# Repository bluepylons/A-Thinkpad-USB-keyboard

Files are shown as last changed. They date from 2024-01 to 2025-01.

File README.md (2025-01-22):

# Work in Progress

## Note January 21, 2025: the downstream USB-C port likely violates USB-C spec since it provides 5V all the time, instead of only when CC resistors are detected.

# About

This is a project attempting to make a USB keyboard/Trackpoint controller and enclosure for the non-chiclet Thinkpad keyboard (from the 10/20 generation, such as the T410, W520, etc.). These were, in my opinion, the best Thinkpad keyboards ever made.

# Controller

The current plan is to use an RP2040 microcontroller running QMK to handle the key matrix scanning and Trackpoint. I would also like to add a USB 2.0 hub.

# Future goals

I would like to eventually adapt this keyboard to be used on the Framework 13 laptop, which would require designing a custom lower chassis for the Framework laptop. That is well in the future, but the engineering required for this project lays much of the groundwork for that project.

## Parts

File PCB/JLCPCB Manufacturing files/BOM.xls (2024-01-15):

Comment | Designator | Footprint | LCSC Part Number | Type
10uF | C1, C2, C14,C15,C16,C17,C18,C19,C20, C25, C32,C33,C34 | C1206 | C13585 (https://lcsc.com/product-detail/Multilayer-Ceramic-Capacitors-MLCC-SMD-SMT_SAMSUNG_CL31A106KBHNNNE_10uF-106-10-50V_C13585.html) | Basic
18pF | C3, C4 | C0402 | C1549 | Basic
22pF | C5, C9 | C0402 | C1555 | Basic
100nF | C6,C7,C8, C10,C11,C12,C13, C22,C23,C24, C26,C27,C28, C30, C31 | C0402 | C1525 | Basic
1uF | C21,C29 | C0603 | C15849 | Basic
SMF9.0CA | D1 | SOD-123FL | C123799 | Extended
RB060M-60TR (https://jlcpcb.com/partdetail/RohmSemicon-RB060M60TR/C114257) | D3,D4 | SOD-123F | C114257 | Extended
1812L075PR | F1 | 1812 | C142689 | Extended
TYPE-C-31-M-12 | J1,J7 | SMD | C165948 | Extended
CBM321611U600T | L1 | 1206 | C394451 | Extended
BSS138 | Q1,Q2,Q3 | SOT-23 | C52895 | Extended
5.1K | R1, R2 | R0805 | C27834 (https://lcsc.com/product-detail/Chip-Resistor-Surface-Mount_UNI-ROYAL-Uniroyal-Elec-0805W8F5101T5E_C27834.html) | Basic
27 | R3,R13 | R0402 | C2991567 | Extended
10K | R4, R11, R20,R21,R22,R23 | R0603 | C25804 | Basic
12K | R5 | R0805 | C17444 | Basic
56K | R6,R7,R8,R9 | R0805 | C17756 | Extended
100 | R10,R18 | R0805 | C17408 | Basic
100k | R12 | R0805 | C149504 | Basic
1k | R14,R15,R16 | R0805 | C17513 | Basic
1M | R19 | R0805 | C17514 | Basic
SRV05-4 | U1,U4,U5,U10 | SOT-23-6 | C7420376 | Extended
RP2040 | U2 | LQFN-56(7x7) | C2040 | Extended
USB2514B-AEZC-TR (https://jlcpcb.com/partdetail/MicrochipTech-USB2514B_AEZCTR/C16251) | U3 | VQFN-36-EP(6x6) | C16251 | Extended
W25Q128JVS | U6 | SOIC-8-208mil | C97521 | Basic
TLV1117LV33DCYR | U8 | SOT-223 | C15578 | Extended
24MHz | Y1 | SMD3225-4P | C91744 | Extended
12MHz | Y2 | SMD3225-4P | C9002 | Basic

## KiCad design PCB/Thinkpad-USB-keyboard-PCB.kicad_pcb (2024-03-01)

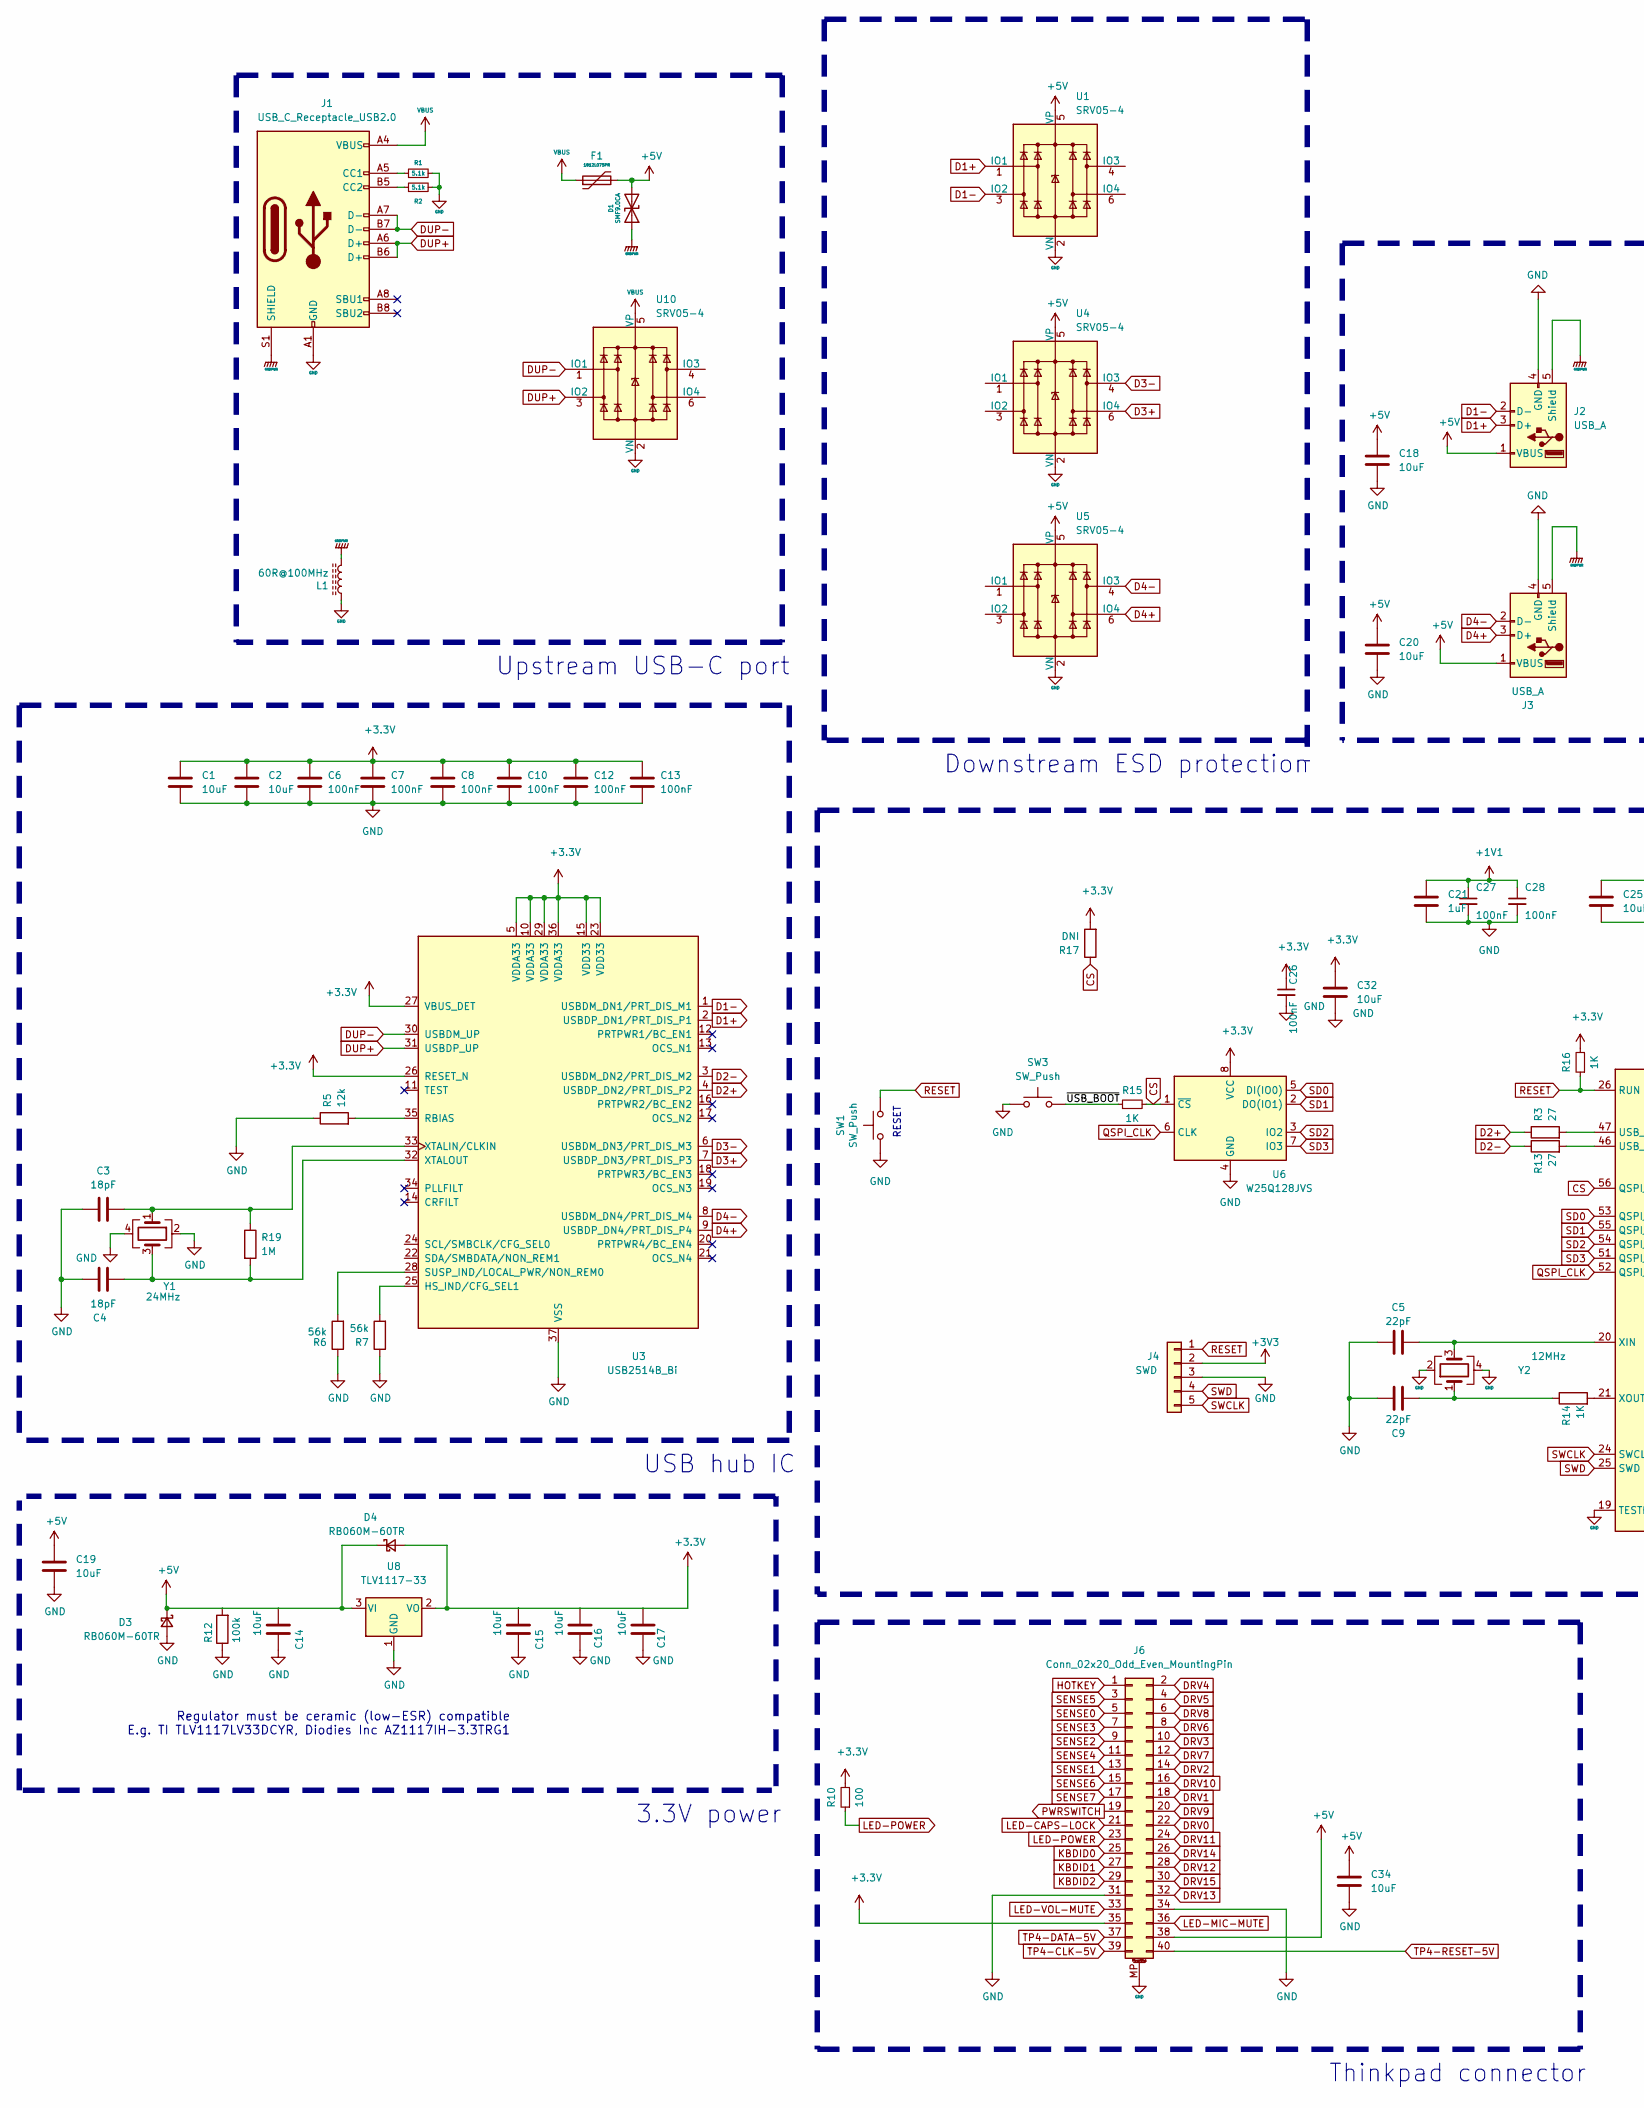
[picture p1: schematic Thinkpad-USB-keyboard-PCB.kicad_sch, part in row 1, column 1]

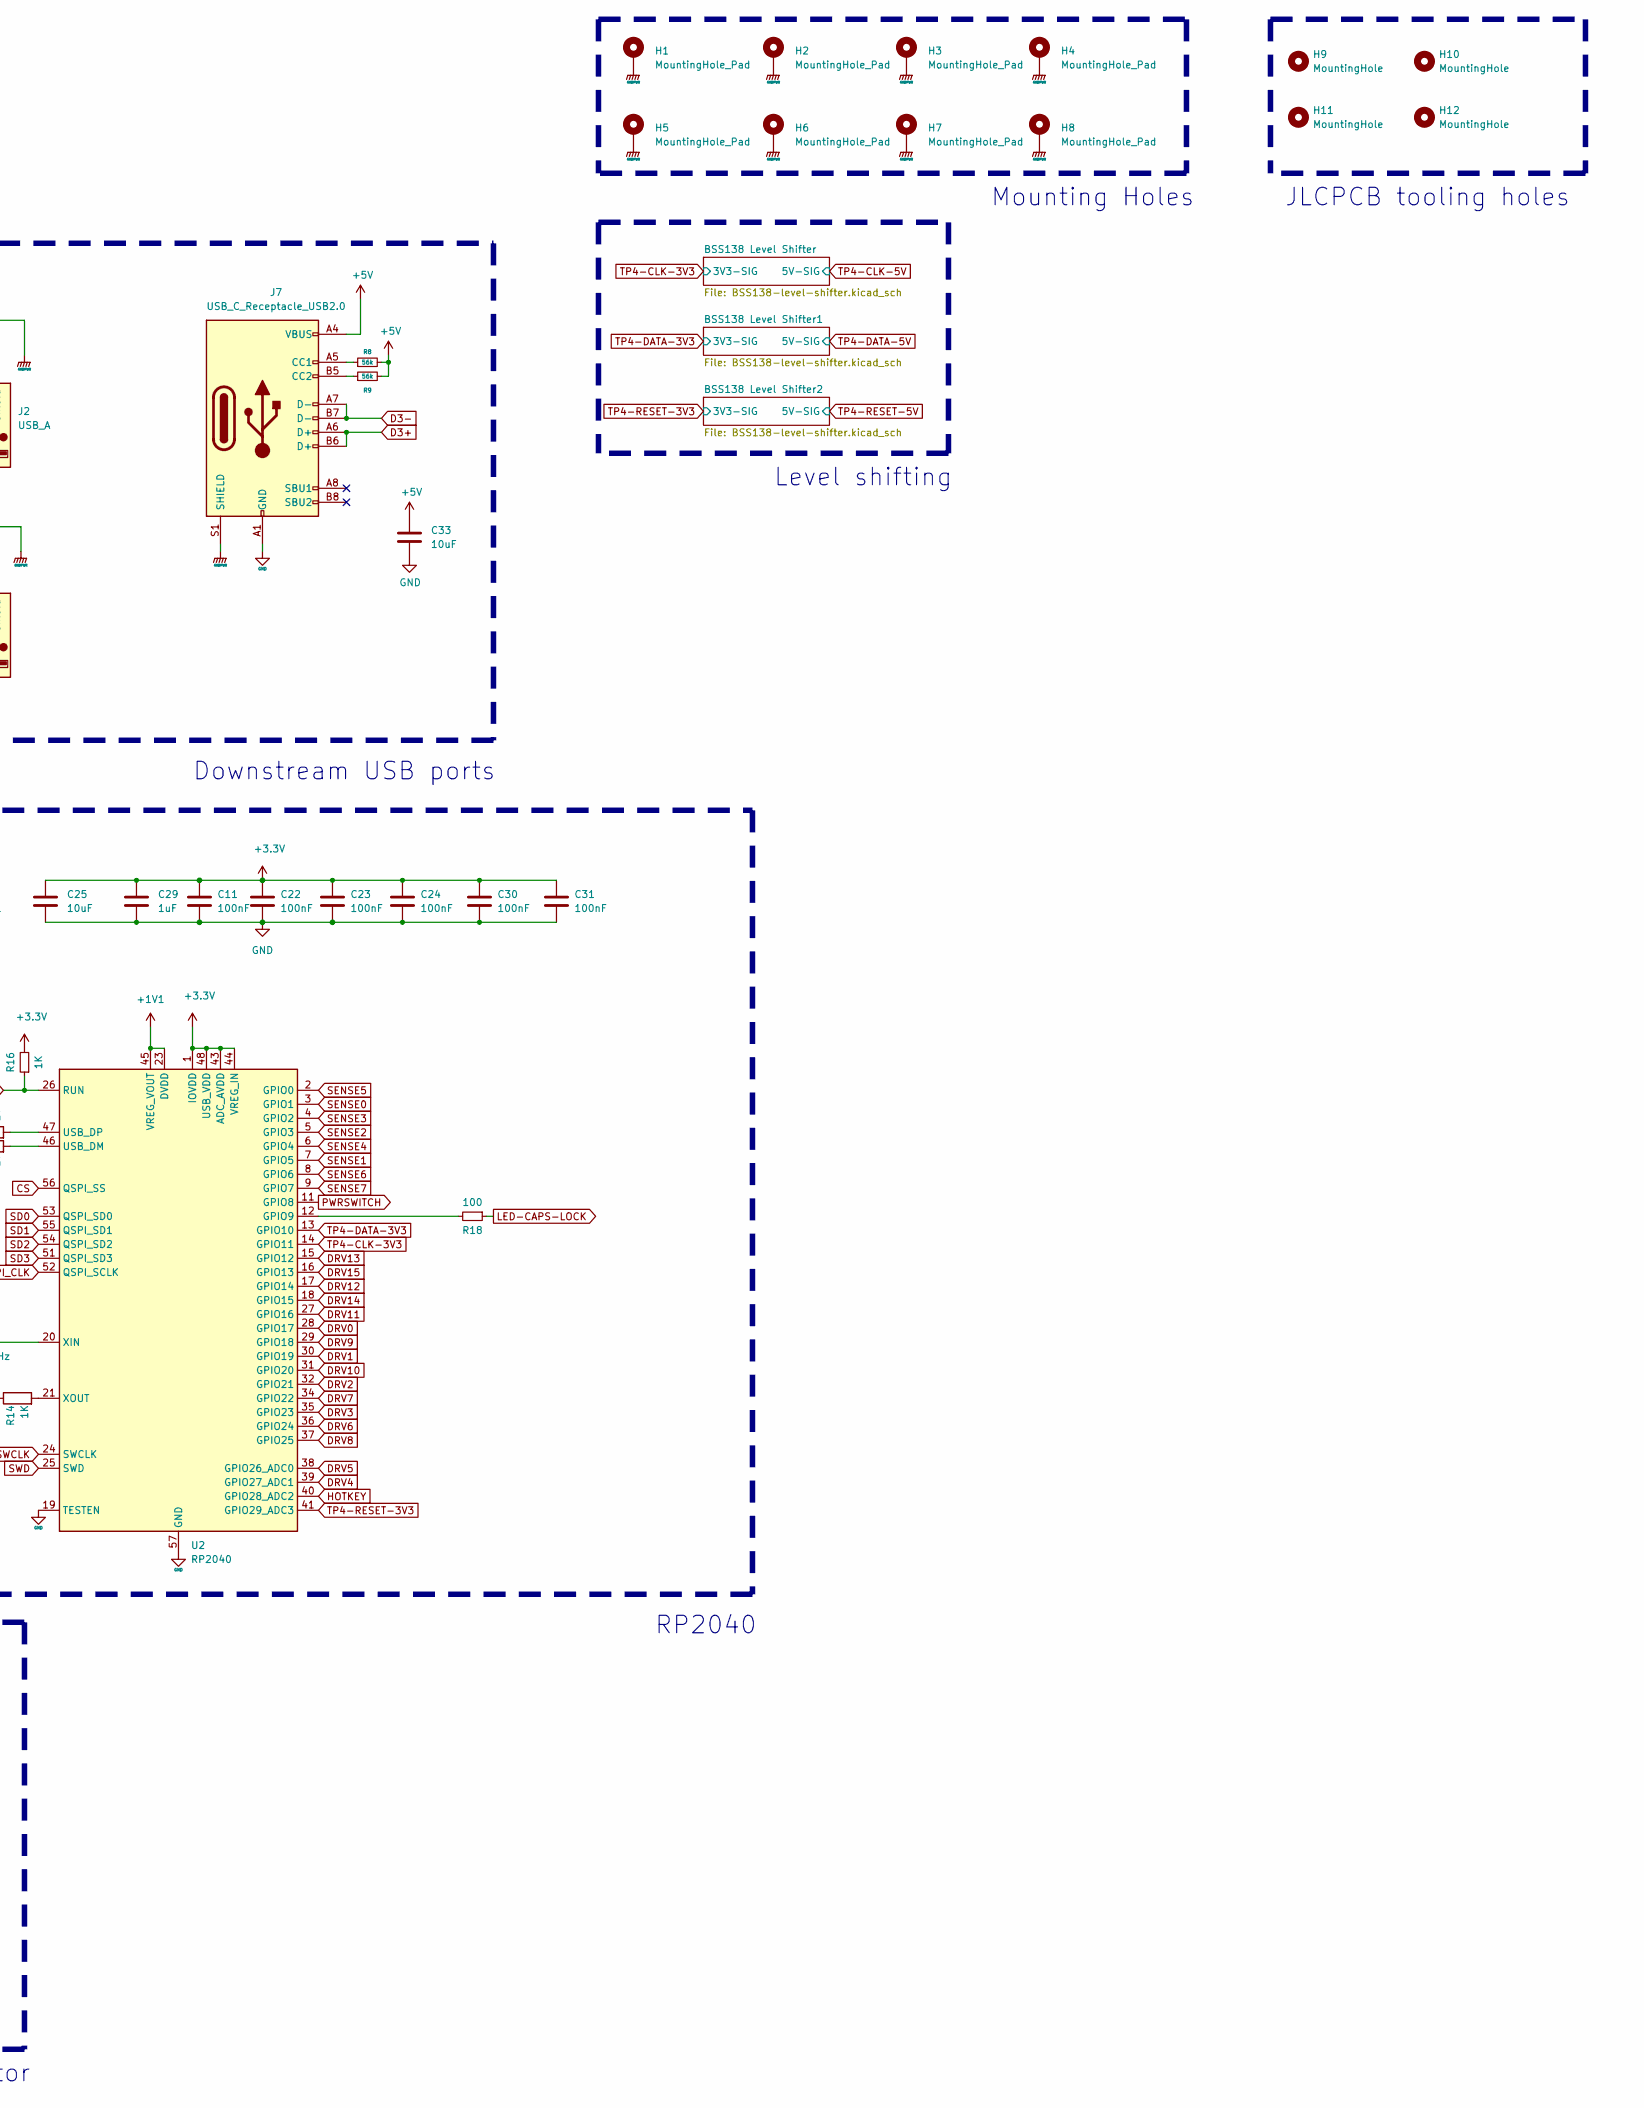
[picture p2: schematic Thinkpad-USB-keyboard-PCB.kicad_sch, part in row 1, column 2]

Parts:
C1, C2, C14, C15, C16, C17, C18, C19, C20, C25, C32, C33, C34: 10uF; C_1206_3216Metric_Pad1.33x1.80mm_HandSolder
C3, C4: 18pF; C_0402_1005Metric_Pad0.74x0.62mm_HandSolder
C5, C9: 22pF; C_0402_1005Metric_Pad0.74x0.62mm_HandSolder
C6, C7, C8, C10, C11, C12, C13, C22, C23, C24, C30, C31: 100nF; C_0402_1005Metric_Pad0.74x0.62mm_HandSolder
C21, C29: 1uF; C_0603_1608Metric_Pad1.08x0.95mm_HandSolder
C26, C27, C28: 100nF; C_0402_1005Metric_Pad0.74x0.62mm_HandSolder; LCSC C1525
D1: SMF9.0CA; D_SOD-123; Manufacturer Part No SMF9.0CA; LCSC Part No C123799
D3, D4: RB060M-60TR; D_SOD-123
F1: 1812L075PR; Fuse_1812_4532Metric_Pad1.30x3.40mm_HandSolder; Manufacturer Part No ASMD1206-150; LCSC Part No C135342
H1, H2, H3, H4, H5, H6, H7, H8: MountingHole_Pad; MountingHole_3.2mm_M3_ISO7380_Pad
H9, H10, H11, H12: MountingHole; JLCPCB-tooling-hole
J1, J7: USB_C_Receptacle_USB2.0; USB_C_Receptacle_HRO_TYPE-C-31-M-12; LCSC C165948
J2, J3: USB_A; USB_A_Molex_67643_Horizontal
J4: SWD; PinSocket_1x05_P2.54mm_Vertical
J6: Conn_02x20_Odd_Even_MountingPin; Molex Slimstack 54363-0489
L1: 60R@100MHz; L_1206_3216Metric; Manufacturer Part No MLB3216-600P4A(f); LCSC Part No C33600
R1, R2: 5.1k; R_0805_2012Metric_Pad1.20x1.40mm_HandSolder
R3, R13: 27; C_0402_1005Metric_Pad0.74x0.62mm_HandSolder
R5: 12k; R_0805_2012Metric_Pad1.20x1.40mm_HandSolder
R6, R7, R8, R9: 56k; R_0805_2012Metric_Pad1.20x1.40mm_HandSolder
R10, R18: 100; R_0805_2012Metric_Pad1.20x1.40mm_HandSolder; LCSC C11702
R12: 100k; R_0805_2012Metric_Pad1.20x1.40mm_HandSolder
R14: 1K; R_0805_2012Metric_Pad1.20x1.40mm_HandSolder
R15, R16: 1K; R_0805_2012Metric_Pad1.20x1.40mm_HandSolder; LCSC C11702
R17: DNI; C_0805_2012Metric_Pad1.18x1.45mm_HandSolder
R19: 1M; R_0805_2012Metric_Pad1.20x1.40mm_HandSolder
SW1, SW3: SW_Push; SW_PUSH_6mm_H5mm
U1, U4, U5, U10: SRV05-4; SOT-23-6
U2: RP2040; QFN-56-1EP_7x7mm_P0.4mm_EP3.2x3.2mm
U3: USB2514B_Bi; QFN-36-1EP_6x6mm_P0.5mm_EP3.7x3.7mm
U6: W25Q128JVS; SOIC-8_5.23x5.23mm_P1.27mm; LCSC C131025
U8: TLV1117-33; SOT-223-3_TabPin2
Y1: 24MHz; Crystal_SMD_3225-4Pin_3.2x2.5mm_HandSoldering
Y2: 12MHz; Crystal_SMD_3225-4Pin_3.2x2.5mm_HandSoldering

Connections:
+1V1: C21.1, C27.1, C28.1, U2.23 (DVDD), U2.45 (VREG_VOUT), U2.50 (DVDD)
+5V: C14.1, C18.1, C19.1, C20.1, C33.1, C34.1, D1.2 (A2), D3.1 (K), D4.1 (K), F1.2, J2.1 (VBUS), J3.1 (VBUS), J6.38, J7.A4 (VBUS), J7.A9 (VBUS), J7.B4 (VBUS), J7.B9 (VBUS), R8.2, R9.2, R12.2, U1.5 (VP), U4.5 (VP), U5.5 (VP), U8.3 (VI); also elsewhere on the board
/~USB_BOOT: R15.1, SW3.2
CS: R15.2, R17.1, U2.56 (QSPI_SS), U6.1 (~CS)
D1+: J2.3 (D+), U1.1 (IO1), U3.2 (USBDP_DN1/PRT_DIS_P1)
D1-: J2.2 (D-), U1.3 (IO2), U3.1 (USBDM_DN1/PRT_DIS_M1)
D2+: R3.1, U3.4 (USBDP_DN2/PRT_DIS_P2)
D2-: R13.1, U3.3 (USBDM_DN2/PRT_DIS_M2)
D3+: J7.A6 (D+), J7.B6 (D+), U3.7 (USBDP_DN3/PRT_DIS_P3), U4.6 (IO4)
D3-: J7.A7 (D-), J7.B7 (D-), U3.6 (USBDM_DN3/PRT_DIS_M3), U4.4 (IO3)
D4+: J3.3 (D+), U3.9 (USBDP_DN4/PRT_DIS_P4), U5.6 (IO4)
D4-: J3.2 (D-), U3.8 (USBDM_DN4/PRT_DIS_M4), U5.4 (IO3)
DRV0: J6.22, U2.28 (GPIO17)
DRV1: J6.18, U2.30 (GPIO19)
DRV2: J6.14, U2.32 (GPIO21)
DRV3: J6.10, U2.35 (GPIO23)
DRV4: J6.2, U2.39 (GPIO27_ADC1)
DRV5: J6.4, U2.38 (GPIO26_ADC0)
DRV6: J6.8, U2.36 (GPIO24)
DRV7: J6.12, U2.34 (GPIO22)
DRV8: J6.6, U2.37 (GPIO25)
DRV9: J6.20, U2.29 (GPIO18)
DRV10: J6.16, U2.31 (GPIO20)
DRV11: J6.24, U2.27 (GPIO16)
DRV12: J6.28, U2.17 (GPIO14)
DRV13: J6.32, U2.15 (GPIO12)
DRV14: J6.26, U2.18 (GPIO15)
DRV15: J6.30, U2.16 (GPIO13)
DUP+: J1.A6 (D+), J1.B6 (D+), U3.31 (USBDP_UP), U10.3 (IO2)
DUP-: J1.A7 (D-), J1.B7 (D-), U3.30 (USBDM_UP), U10.1 (IO1)
GND: C1.2, C2.2, C3.1, C4.1, C5.1, C6.2, C7.2, C8.2, C9.1, C10.2, C11.2, C12.2, C13.2, C14.2, C15.2, C16.2, C17.2, C18.2, C19.2, C20.2, C21.2, C22.2, C23.2, C24.2, C25.2, C26.2, C27.2, C28.2, C29.2, C30.2, C31.2, C32.2, C33.2, C34.2, D3.2 (A), J1.A1 (GND), J1.A12 (GND), J1.B1 (GND), J1.B12 (GND), J2.4 (GND), J3.4 (GND), J4.3, J6.31, J6.34, J6.MP (MountPin), J7.A1 (GND), J7.A12 (GND), J7.B1 (GND), J7.B12 (GND), L1.1, R1.2, R2.2, R5.1, R6.1, R7.1, R12.1, SW1.1, SW3.1, U1.2 (VN), U2.19 (TESTEN), U2.57 (GND), U3.37 (VSS), U4.2 (VN), U5.2 (VN), U6.4 (GND), U8.1 (GND), U10.2 (VN), Y1.2, Y1.4, Y2.2, Y2.4
GNDPWR: D1.1 (A1), H1.1, H2.1, H3.1, H4.1, H5.1, H6.1, H7.1, H8.1, J1.S1 (SHIELD), J2.5 (Shield), J3.5 (Shield), J7.S1 (SHIELD), L1.2
HOTKEY: J6.1, U2.40 (GPIO28_ADC2)
KBDID0: J6.25
KBDID1: J6.27
KBDID2: J6.29
LED-CAPS-LOCK: J6.21, R18.1
LED-MIC-MUTE: J6.36
LED-POWER: J6.23, R10.1
LED-VOL-MUTE: J6.33
unnamed: C9.2, R14.1, Y2.1
unnamed: J1.A5 (CC1), R1.1
unnamed: J1.B5 (CC2), R2.1
unnamed: J7.A5 (CC1), R8.1
unnamed: J7.B5 (CC2), R9.1
unnamed: R18.2, U2.12 (GPIO9)
unnamed: R13.2, U2.46 (USB_DM)
unnamed: R3.2, U2.47 (USB_DP)
unnamed: C5.2, U2.20 (XIN), Y2.3
unnamed: R14.2, U2.21 (XOUT)
unnamed: R7.2, U3.25 (HS_IND/CFG_SEL1)
unnamed: R5.2, U3.35 (RBIAS)
unnamed: R6.2, U3.28 (SUSP_IND/LOCAL_PWR/NON_REM0)
unnamed: C3.2, R19.1, U3.33 (XTALIN/CLKIN), Y1.1
unnamed: C4.2, R19.2, U3.32 (XTALOUT), Y1.3
PWRSWITCH: J6.19, U2.11 (GPIO8)
QSPI_CLK: U2.52 (QSPI_SCLK), U6.6 (CLK)
RESET: J4.1, R16.1, SW1.2, U2.26 (RUN)
SD0: U2.53 (QSPI_SD0), U6.5 (DI(IO0))
SD1: U2.55 (QSPI_SD1), U6.2 (DO(IO1))
SD2: U2.54 (QSPI_SD2), U6.3 (IO2)
SD3: U2.51 (QSPI_SD3), U6.7 (IO3)
SENSE0: J6.5, U2.3 (GPIO1)
SENSE1: J6.13, U2.7 (GPIO5)
SENSE2: J6.9, U2.5 (GPIO3)
SENSE3: J6.7, U2.4 (GPIO2)
SENSE4: J6.11, U2.6 (GPIO4)
SENSE5: J6.3, U2.2 (GPIO0)
SENSE6: J6.15, U2.8 (GPIO6)
SENSE7: J6.17, U2.9 (GPIO7)
SWCLK: J4.5, U2.24 (SWCLK)
SWD: J4.4, U2.25 (SWD)
TP4-CLK-3V3: U2.14 (GPIO11); also elsewhere on the board
TP4-CLK-5V: J6.39; also elsewhere on the board
TP4-DATA-3V3: U2.13 (GPIO10); also elsewhere on the board
TP4-DATA-5V: J6.37; also elsewhere on the board
TP4-RESET-3V3: U2.41 (GPIO29_ADC3); also elsewhere on the board
TP4-RESET-5V: J6.40; also elsewhere on the board
VBUS: F1.1, J1.A4 (VBUS), J1.A9 (VBUS), J1.B4 (VBUS), J1.B9 (VBUS), U10.5 (VP)

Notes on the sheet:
RP2040
JLCPCB tooling holes
Downstream USB ports
Upstream USB-C port
Mounting Holes
USB hub IC
Regulator must be ceramic (low-ESR) compatible E.g. TI TLV1117LV33DCYR, Diodies Inc AZ1117IH-3.3TRG1
Thinkpad connector
Level shifting
RESET
Downstream ESD protection
3.3V power

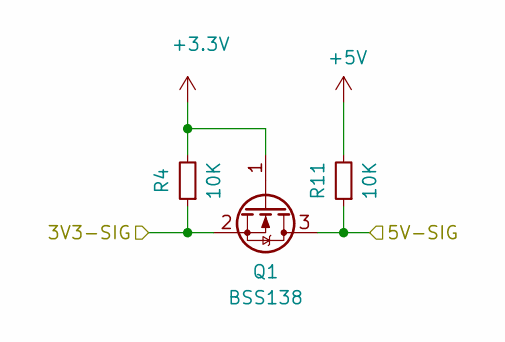
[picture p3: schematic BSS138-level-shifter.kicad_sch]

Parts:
Q1: BSS138; SOT-23
R4, R11: 10K; R_0603_1608Metric_Pad0.98x0.95mm_HandSolder; LCSC C11702

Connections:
+5V: R11.2; also elsewhere on the board
TP4-CLK-3V3: Q1.2 (S), R4.1; also elsewhere on the board
TP4-CLK-5V: Q1.3 (D), R11.1; also elsewhere on the board

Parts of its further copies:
Q2, Q3: BSS138; SOT-23
R20, R21, R22, R23: 10K; R_0603_1608Metric_Pad0.98x0.95mm_HandSolder; LCSC C11702

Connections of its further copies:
+5V: R21.2, R23.2; also elsewhere on the board
TP4-DATA-3V3: Q2.2 (S), R20.1; also elsewhere on the board
TP4-DATA-5V: Q2.3 (D), R21.1; also elsewhere on the board
TP4-RESET-3V3: Q3.2 (S), R22.1; also elsewhere on the board
TP4-RESET-5V: Q3.3 (D), R23.1; also elsewhere on the board

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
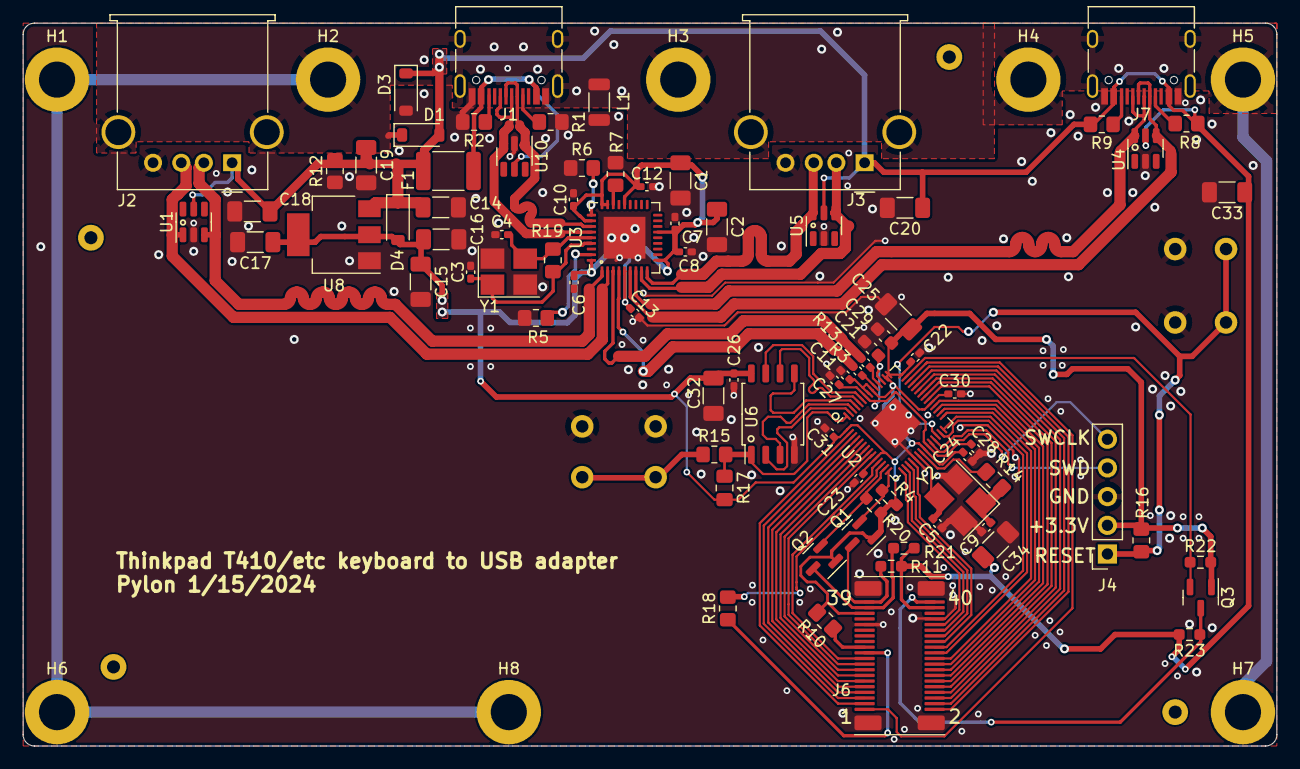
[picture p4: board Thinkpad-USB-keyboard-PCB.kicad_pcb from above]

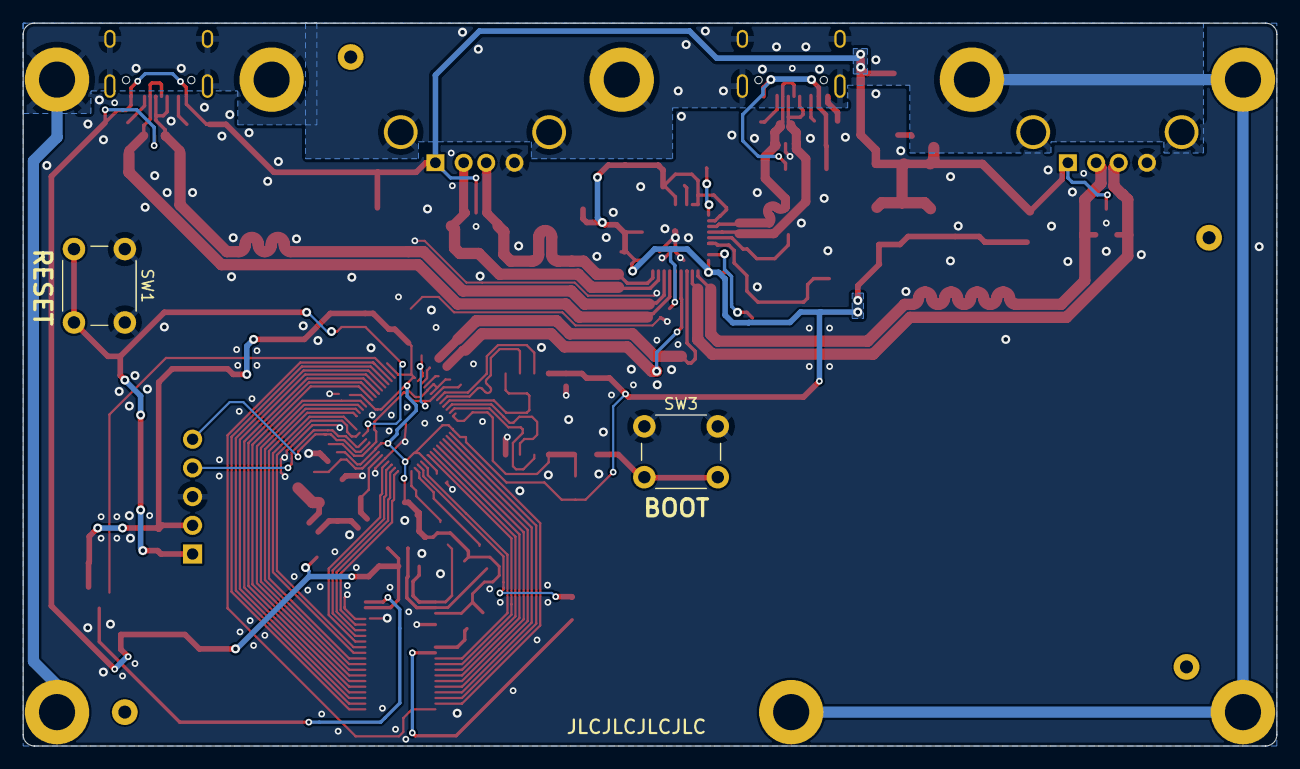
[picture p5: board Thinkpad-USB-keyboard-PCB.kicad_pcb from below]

Board: 2 copper layers, 111.0 x 64.0 mm, 95 parts (2 on the bottom side), 75 nets.

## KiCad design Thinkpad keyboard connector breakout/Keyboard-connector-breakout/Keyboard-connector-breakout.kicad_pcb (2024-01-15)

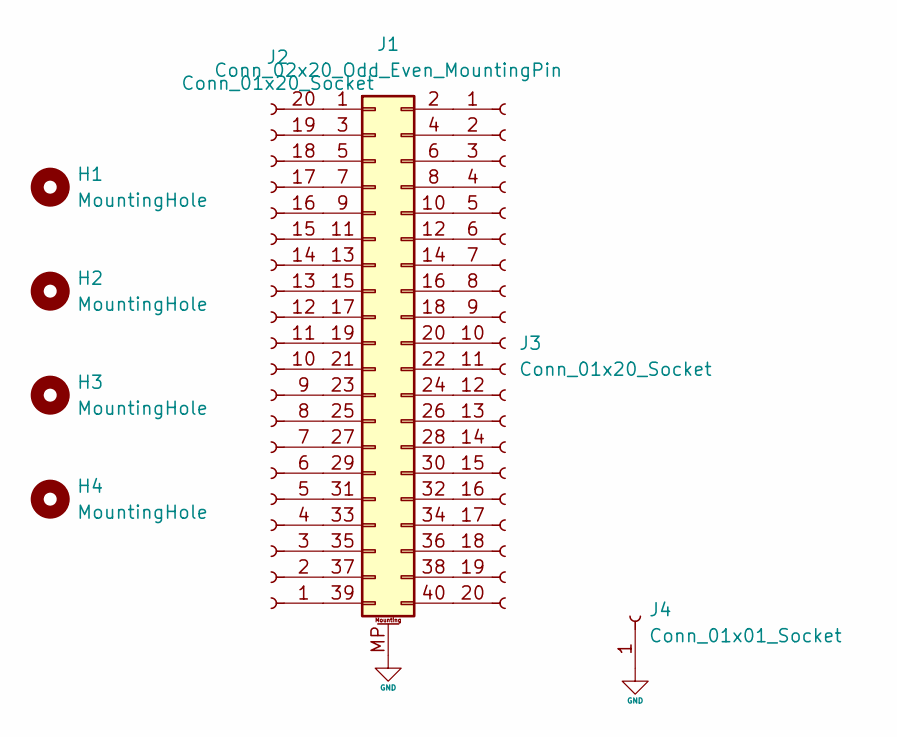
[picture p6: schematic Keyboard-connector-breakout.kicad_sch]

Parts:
H1, H2, H3, H4: MountingHole; MountingHole_3.2mm_M3_ISO7380
J1: Conn_02x20_Odd_Even_MountingPin; Molex Slimstack 54363-0489
J2, J3: Conn_01x20_Socket; PinSocket_1x20_P2.54mm_Vertical
J4: Conn_01x01_Socket; PinHeader_1x01_P2.54mm_Vertical

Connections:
GND: J1.MP (MountPin), J4.1
unnamed: J1.1, J2.20
unnamed: J1.2, J3.1
unnamed: J1.3, J2.19
unnamed: J1.4, J3.2
unnamed: J1.5, J2.18
unnamed: J1.6, J3.3
unnamed: J1.7, J2.17
unnamed: J1.8, J3.4
unnamed: J1.9, J2.16
unnamed: J1.10, J3.5
unnamed: J1.11, J2.15
unnamed: J1.12, J3.6
unnamed: J1.13, J2.14
unnamed: J1.14, J3.7
unnamed: J1.15, J2.13
unnamed: J1.16, J3.8
unnamed: J1.17, J2.12
unnamed: J1.18, J3.9
unnamed: J1.19, J2.11
unnamed: J1.20, J3.10
unnamed: J1.21, J2.10
unnamed: J1.22, J3.11
unnamed: J1.23, J2.9
unnamed: J1.24, J3.12
unnamed: J1.25, J2.8
unnamed: J1.26, J3.13
unnamed: J1.27, J2.7
unnamed: J1.28, J3.14
unnamed: J1.29, J2.6
unnamed: J1.30, J3.15
unnamed: J1.31, J2.5
unnamed: J1.32, J3.16
unnamed: J1.33, J2.4
unnamed: J1.34, J3.17
unnamed: J1.35, J2.3
unnamed: J1.36, J3.18
unnamed: J1.37, J2.2
unnamed: J1.38, J3.19
unnamed: J1.39, J2.1
unnamed: J1.40, J3.20

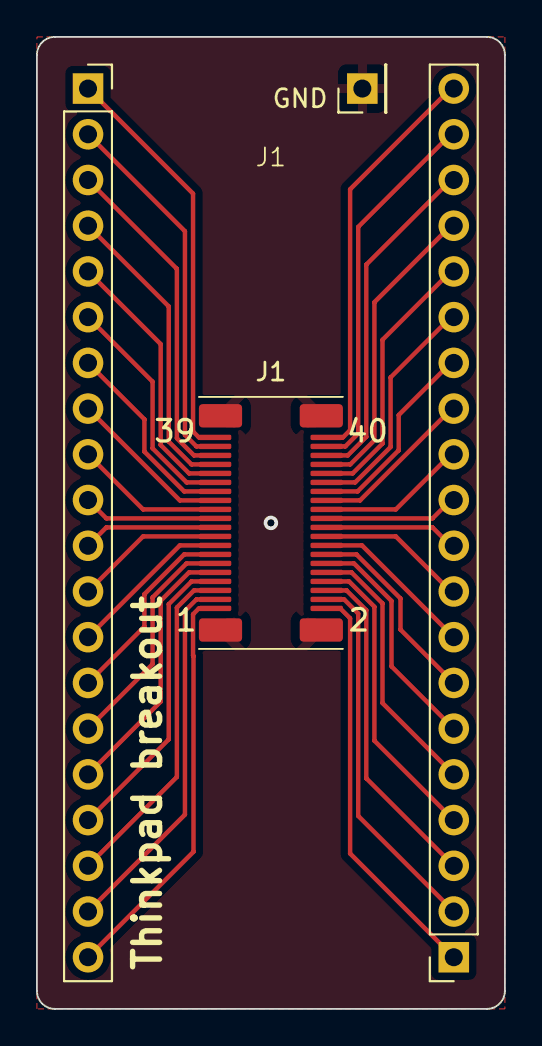
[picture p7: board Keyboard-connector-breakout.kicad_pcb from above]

Board: 2 copper layers, 26.0 x 54.0 mm, 8 parts (0 on the bottom side), 41 nets.

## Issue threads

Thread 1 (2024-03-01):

Missing License

goran-mahovlic, 2024-03-01:
Hi,

thank you for this great project!

I would need to do some similar work for Balthazar project, and while searching got to your repository.
As they need almost the same thing you have I am wondering maybe we could use or just rework your project to also fit Balthazar.

https://balthazar.space/wiki/News

What I do not know is what license will you select, just so we can check if license are compatible...

Balthazar is using - CERN Open Hardware Licence

Best,
Goran

bluepylons, 2024-03-01:
Hey!

Sorry I forgot to update the repo. I'm leaning towards CERN OHL-W, though I need to double check whether I used anything from a certain GPL 3 project.

The supply of T410/X220/etc. keyboards is somewhat limited as it is from a 12-14-year old laptop, so I'm not sure if this is the best option for a new laptop. This project was actually spawned out of [various efforts to adapt a Thinkpad keyboard to a Framework](https://community.frame.work/t/thinkpad-keyboard-mod-super-early-stages/) - going through that thread would be helpful. [CS Scott is working on an X1 Carbon Gen 10 keyboard](https://github.com/cscott/X1CarbonGen10/tree/main), and posted some helpful links [here](https://community.frame.work/t/thinkpad-keyboard-mod-super-early-stages/38484/22).

NXT, 2024-05-22:
Hi,
thanks for making this PCB .
I run a Balthazar project lead, and we try to develop the optional add-on for replacing our keyboard with X220 or X230 line. Those are plenty and rather cheap. If you could tell us more about X2xx compatibility and adding the USB-C to the PCB it'll would be great. Basically we could use it to implement and complete our design.
Thanks a lot.

bluepylons, 2024-05-22:
Hi Harv,

What information are you looking for? I’d be happy to answer any questions.

The PCB has an upstream USB-C port, though it includes a hub that you
probably don’t need.

Unfortunately I haven’t had much time to work on this project the last few
months, so I haven’t been able to write the firmware or anything yet.

Best,
James

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

NXT, 2024-05-23:
Hey James,

due to the modularity of our envisaged system, we probably need just a USB-C on your PCB. Would x2xx ThinkPad keyboard work with it? Those are the same on all X2xx models, changing a layout but in later models.x240 and 60.
What would take for you to customize it for our Balthazar project? We can also make a donation to your project as a compensation for your work.
Just let me know.
Thanx once more.

Harv

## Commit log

2024-01-06 More work
    [Thinkpad-USB-keyboard-PCB.kicad_pcb, Thinkpad-USB-keyboard-PCB.kicad_sch]
2024-01-07 Made a breakout board for the Thinkpad keyboard connector
    [Keyboard-connector-breakout.kicad_pcb, Keyboard-connector-breakout.kicad_sch, Thinkpad-USB-keyboard-PCB.kicad_sch]
2024-01-11 More layout work
    [Thinkpad-USB-keyboard-PCB.kicad_pcb, Thinkpad-USB-keyboard-PCB.kicad_sch]
2024-01-13 Fixed some errors
    [Thinkpad-USB-keyboard-PCB.kicad_pcb]
2024-01-15 Finalized initial version
    [Thinkpad-USB-keyboard-PCB.kicad_pcb, Thinkpad-USB-keyboard-PCB.kicad_sch]
2024-01-15 finalized files
    [BOM.xls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]
2024-03-01 Added license; more development work
    [Thinkpad-USB-keyboard-PCB-B_Cu.gbr, Thinkpad-USB-keyboard-PCB-B_Mask.gbr, Thinkpad-USB-keyboard-PCB-B_Paste.gbr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]
